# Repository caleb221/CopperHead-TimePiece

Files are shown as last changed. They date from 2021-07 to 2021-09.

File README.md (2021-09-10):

# CopperHead-TimePiece
A 'Retro' ESP32 Based Smart watch using an HPDL-1414 and an .91'' OLED <br>**42x35mm**<br>
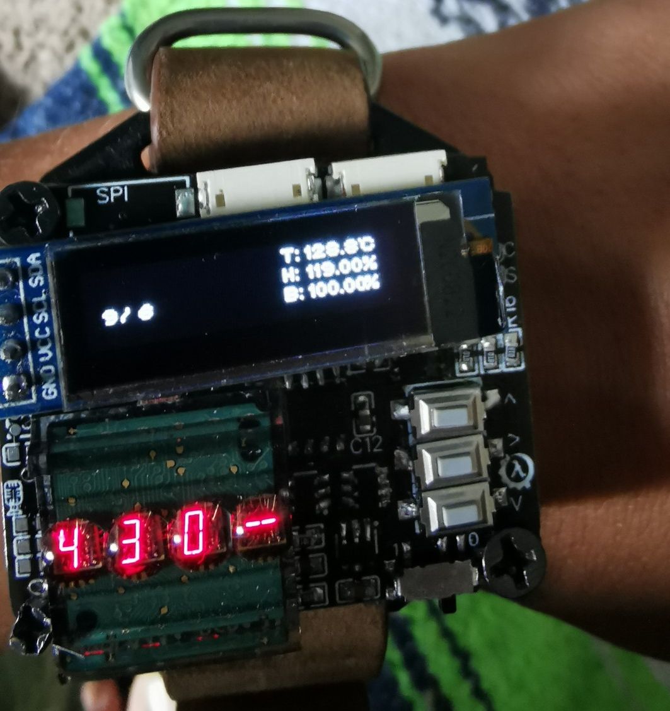
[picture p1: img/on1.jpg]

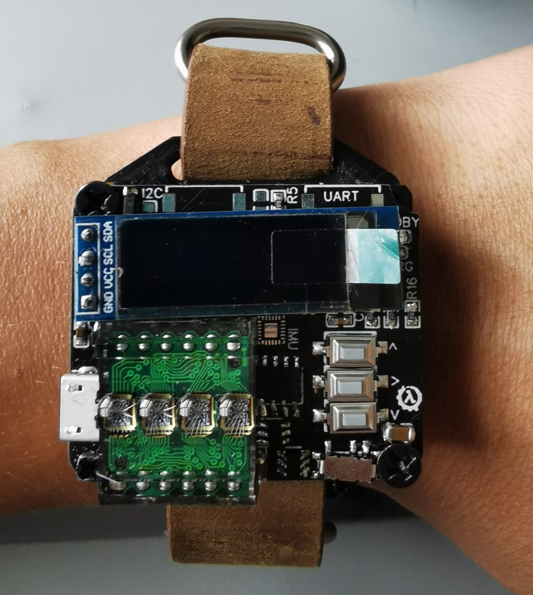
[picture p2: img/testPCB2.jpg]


# IN PROGRESS
    --> BE SURE TO GET THE MOST UP TO DATE FILES AS THERE ARE SEVERAL ITERATIONS
    --> TEST MEMS MIC / IMU    
  Add personal Assistant with Mic using:
  <a href="https://www.survivingwithandroid.com/esp32-tensorflow-micro-speech-i2s-external-microphone/">ESP32-I2S WITH TENSORFLOW MICRO</a>

# Features
  Watch based around the ESP32 and HPDL1414. <br>
  Update time with NTP in known WiFi Areas (SSIDS/Passwords saved in SPIFFS JSON file) <br>
  DS1307 Real Time Module<br>
  Temperature and Humidity readings <br>
  Battery Charging and monitoring <br>
  MPU-950 Gyroscope/Accelerometer/Magenetometer (Compass)<br>
  MEMS Analog Microphone (to be used with TF-Lite Speech Recognition for wake words / personal assistant)<br>
  I2C/UART/SPI modular breakout for future sensors/ICs <br>
  Chrome Dino Game  <br>
  Space Invaders Game <br>
  Update WiFi networks and system time over a hosted website incase there are no known networks around and time is off.
   
# Schematic
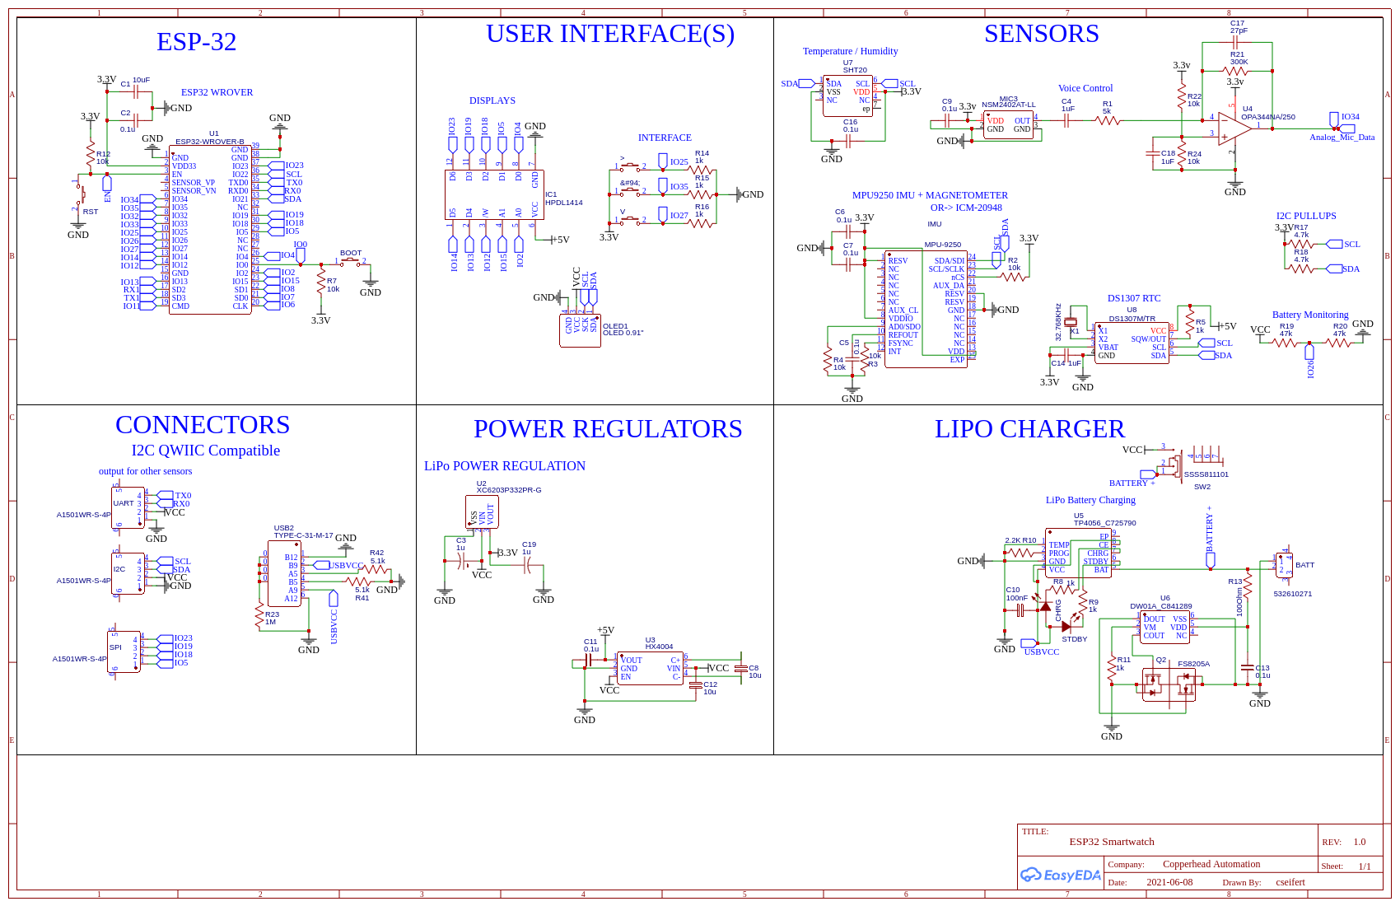
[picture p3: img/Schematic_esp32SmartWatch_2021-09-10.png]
  
  
  
       
# Hardware
     ESP32 Wrover-B (4 or 8Mb) 
     HPDL-1414 Segmented Display  
     0.91'' OLED Display 
     DS1307 RTC Module
     SHT20 Temperature/Humidity Sensor 
     MPU-9250 Gyroscope/Accelerometer/Magnetometer 
     Tactile Switches (3 with 2 optional) 
     Various SMD Resistors/Capacitors (0603 Resistors)
     32.768kHz ±20ppm Crystal
     TP4056 
     DW01A  
     FS8205A
     HX4004 DC-DC Step up (LDO) 
     XC6203P332PR DC-DC Regulator (LDO)
     GMA3722H11-F42 MEMS Analog Microphone
     OPA344NA Analog Op Amp
     TYPE-C-31-M-17 USB-C Connector (6-Pin Power Only) 
     3.7v 320mAh/420mAh LiPo Battery
     ZH1.5 SMD Right Angle Connectors (4 and 2 pin female)  
     right angle tactile switch
     Tactile Buttons
     USB-C Power connector
     PCB (from Gerber File attached)
     M3x4mm Screws (X6)
     10mm Brass Standoffs (X3)
     3D-Printed Case (STL file)
     Watch Strap (20mm Thick)
     External FTDI/CP2102 USB-TTL converter
     
 <a href ="http://www.farnell.com/datasheets/76528.pdf">HPDL-1414 Datasheet</a>

# Software
     The ESP32 holds a SPIFFS filesystem containing the following files:
               --> index.html (should erase when BLE works) 
               --> userConf.json (known WiFi/Passwords) user edit on upload/web interface
               --> sysTime.json (last updated time) user edit on upload/web interface
               --> highScores.json (high score info for games *UNTESTED*)
     The ESP32 spends most of its time in deep sleep, unless woken from the UI buttons
     Upon wakeup the ESP32 will update the OLED with month, day of week, battery level, temperature, and humidity.
     The HPDL-1414 is used for time in HH:MM format. "1259" = 12:59
     There is also a timer on the watch so that it cannot be awake for too long (always default to sleep)
     The Chrome 404 Dino Game (made for this watch / screen / UI)
     Space Invaders (made for this watch / screen / UI)

   <a href="https://github.com/caleb221/ArduinoChromeDinoGame">My Arduino  Chrome Dino Game</a> 

# Gerber / BOM
      check out the Manufacturing Files folder for these!
      --> Gerber_PCB_esp32SmartWatch_2.zip  2-Layer Board **OLD VERSION**
      --> Gerber_PCB_esp32SmartWatch_3.zip  4-Layer Board **MOST CURRENT**
      I got most normal components at LCSC (excluding those listed below)
      PCB made at JLCPCB
      --> I soldered on the components but I'm sure the SMT Assembly is an option given you match up the BOM
 <br>
 <a href="https://lcsc.com/">LCSC Components</a><br>
 <a href="https://jlcpcb.com/">JLCPCB Pcb Manufacturing</a>
 <br><br>
 
  **THINGS NOT BOUGHT FROM LCSC:** 
 
 <a href ="https://www.amazon.com/dp/B08215N9R8/ref=emc_b_5_t" >3.7v 320mAh LiPo (Amazon)</a>
 **OR**
 <a href = "https://www.adafruit.com/product/4236">3.7 420mAh Lipo (Adafruit)</a><br>
 <a href ="https://www.amazon.com/dp/B08NGL1PQ2?psc=1&ref=ppx_yo2_dt_b_product_details">0.91'' OLED Display (Amazon)</a><br>
 <a href ="https://www.amazon.com/dp/B076BNC876?psc=1&ref=ppx_yo2_dt_b_product_details"> 20mm Leather Watch Strap (Amazon) </a><br>
 <a href="https://www.amazon.com/Uxcell-a14050600ux1057-Female-Hexagon-Standoff/dp/B00NQ87PVK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"> Brass Standoffs (Amazon)</a><br>
 <a href ="https://www.amazon.com/10-M3-0-5-4mm-Countersunk-MonsterBolts/dp/B07983R7XC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">M3 x4mm black Screws (Amazon)</a><br>
 <a href ="https://www.ebay.com/itm/303806129405?ssPageName=STRK%3AMEBIDX%3AIT&_trksid=p2060353.m2749.l2649"> EBAY HPDL-1414 (not guaranteed)</a><br>**EBAY AND AMAZON LINKS/PRODUCTS EXPIRE, YOU'LL NEED TO SEARCH FOR HPDL-1414 WHEREVER YOU NORMALLY SOURCE ODD COMPONENTS**<br> 

# TODO
     Get a stencil <br>
     Make an addon with the modular breakouts (I2C/ UART)
               --> Raspberry pi 0 (with something cool)
               --> SD Card (SPI in Software, would need both ports)
               --> Geiger counter
               --> C02 Monitor
               --> Smart home / MQTT control (would need a UI sub directory added)
               --> Connect LoRa and control the smart farm! (this would take awhile)
# Would Be Nice:
     Waterproof case (hasunCast/PCB potting/ Resin)
     Glass over screens
     smaller PCB (if possible)
     bigger battery (needs to fit inside the case!)
     move buttons to bottom layer / change to right angled tactile buttons
     Use external RTC (DS3231 /C9866) OR (PCF8563M / C434478)
                      (part  / LCSC)
     Android Application (web UI takes place of this for now)
     Use BLE Server implementation (commented out at bottom of code) --> 
          accepts JSON data and updates internal filesystem
          Web Server uses same functions and tested, BLE with JSON is UNTESTED

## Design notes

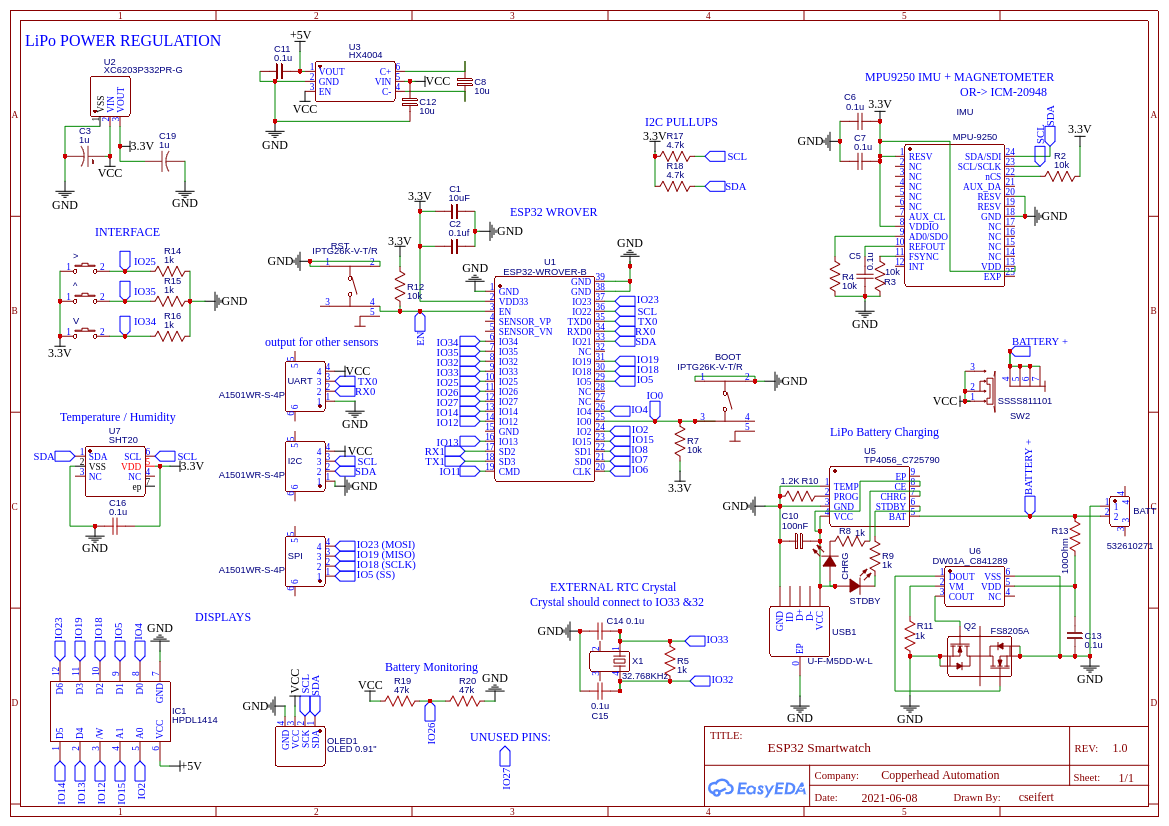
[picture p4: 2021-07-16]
img/Schematic_esp32SmartWatch_2021-07-16.png

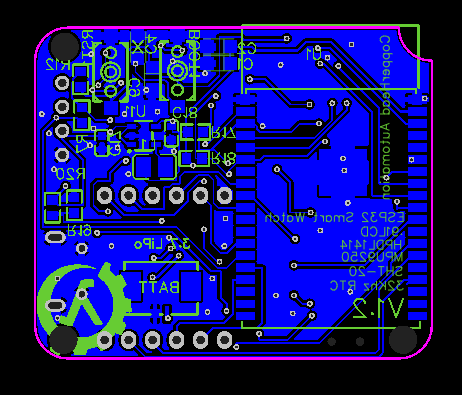
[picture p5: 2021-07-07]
img/PCBeditorBACK.png

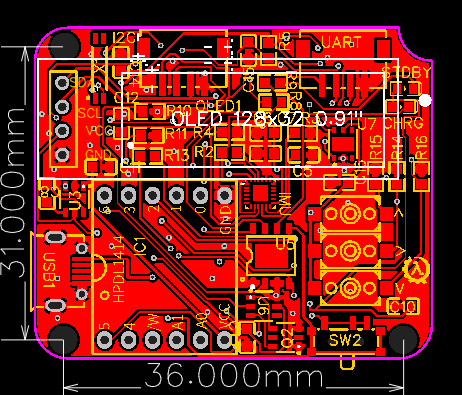
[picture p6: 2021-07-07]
img/PCBeditorFRONT.png

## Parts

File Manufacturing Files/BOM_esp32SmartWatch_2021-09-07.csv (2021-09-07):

ID | Name | Designator | Footprint | Quantity | Manufacturer Part | Manufacturer | Supplier | Supplier Part | Price
1 | K2-3.6×6.1_SMD | ^,>,V | KEY-SMD_2P-L6.2-W3.6-LS8.0 | 3 | K2-1107ST-A4SW-06 |  | LCSC | C118141 | 0.056
2 | 532610271 | BATT | CONN-SMD_532610271 | 1 | 532610271 | MOLEX | LCSC | C189700 | 0.112
3 | IPTG26K-V-T/R | BOOT,RST | SW-SMD_IPTG26K | 2 | IPTG26K-V-T/R | Diptronics | LCSC | C495953 | 0.254
4 | 10uF | C1 | CASE-A_3216 | 1
5 | 0.1uf | C2 | CASE-A_3216 | 1
6 | 1u | C3,C19 | CASE-A_3216 | 2
7 | 1uF | C4,C18 | C0603 | 2
8 | 0.1u | C5,C6,C7,C9,C16,C11,C13 | C0603 | 7
9 | 10u | C8,C12 | C0603 | 2
10 | 100nF | C10 | C0603 | 1
11 | 12pF | C14,C15 | C0603 | 2
12 | 27pF | C17 | C0603 | 1
13 | LED-0603_R | CHRG,STDBY | LED0603_RED | 2 | 19-217/R6C-AL1M2VY/3T | EVERLIGHT(台湾亿光) | LCSC | C72044 | 0.014
14 | A1501WR-S-4P | I2C,SPI,UART | CONN-SMD_A1501WR-S-4P | 3 | A1501WR-S-4P | Changjiang Connectors | LCSC | C225169 | 0.145
15 | HPDL1414 | IC1 | HPDL1414 | 1
16 | MPU-9250 | IMU | QFN-24_L3.0-W3.0-P0.40-BL-EP | 1 | MPU-9250 | InvenSense | LCSC | C71459
17 | NSM2402AT-LL | MIC3 | MIC-SMD_L3.8-W2.2-TL | 1 | NSM2402AT-LL | ReliaPro | LCSC | C140704 | 0.328
18 | OLED 0.91" | OLED1 | OLED_0.91_128X32 | 1 | OLED 0.91" 128x32 |  | LCSC | C91220 | 3.318
19 | FS8205A | Q2 | SOT-23-6_L2.9-W1.6-P0.95-LS2.8-BR | 1 | FS8205A | FORTUNE | LCSC | C32254 | 0.153
20 | 5k | R1 | R0603 | 1
21 | 10k | R2,R3,R4,R7,R12,R22,R24 | R0603 | 7
22 | 1k | R8,R9,R11,R14,R15,R16 | R0603 | 6
23 | 2.2K | R10 | R0603 | 1
24 | 100Ohm | R13 | R0603 | 1
25 | 4.7k | R17,R18 | R0603 | 2
26 | 47k | R19,R20 | R0603 | 2
27 | 300K | R21 | R0603 | 1
28 | 1M | R23 | R0603 | 1
29 | 5.1k | R41,R42 | R0603 | 2
30 | SSSS811101 | SW2 | SW-SMD_SSSS811101 | 1 | SSSS811101 | ALPS | LCSC | C109335 | 0.12
31 | ESP32-WROVER-B | U1 | WIFIM-SMD_39P-L31.4-W18.0-P1.27 | 1 | ESP32-WROVER-B | Espressif Systems | LCSC | C503591 | 3.903
32 | XC6203P332PR-G | U2 | SOT-89-3_L4.5-W2.5-P1.50-LS4.2-BR | 1 | XC6203P332PR-G | Torex Semicon | LCSC | C190503 | 0.243
33 | HX4004 | U3 | SOT-23-6_L2.9-W1.6-P0.95-LS2.8-BR | 1 | HX4004 | HEXIN | LCSC | C172355 | 0.135
34 | OPA344NA/250 | U4 | SOT-23-5_L3.0-W1.7-P0.95-LS2.8-BR | 1 | OPA344NA/250 | TI | LCSC | C131974 | 1.411
35 | TP4056_C725790 | U5 | ESOP-8_L4.9-W3.9-P1.27-LS6.0-BL-EP | 1 | TP4056 | UMW(Youtai Semiconductor Co., Ltd.) | LCSC | C725790 | 0.061
36 | DW01A_C841289 | U6 | SOT-23-6_L2.9-W1.6-P0.95-LS2.8-BR | 1 | DW01A | Shenzhen Fuman Elec | LCSC | C841289 | 0.052
37 | SHT20 | U7 | DFN-6_L3.0-W3.0-P0.95-TR-EP | 1 | SHT20 | Sensirion | LCSC | C53865 | 1.646
38 | TYPE-C-31-M-17 | USB2 | USB-C-SMD_10P-P1.00-L6.8-W8.9 | 1 | TYPE-C-31-M-17 | Korean Hroparts Elec | LCSC | C283540 | 0.194
39 | 32.768KHz | X1 | MC-146_4P-L6.7-W1.5-P0.85-TL | 1 | Q13MC1462000200 | EPSON | LCSC | C15482 | 0.443

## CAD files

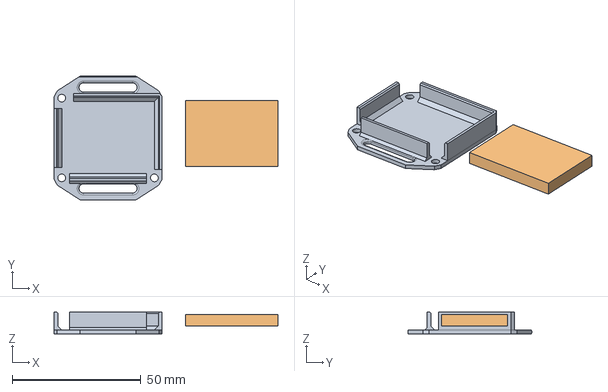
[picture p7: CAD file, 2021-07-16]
STL/watchCaseV2_STRAP_OUTSIDE.FCStd
87.0 x 48.0 x 8.50 mm

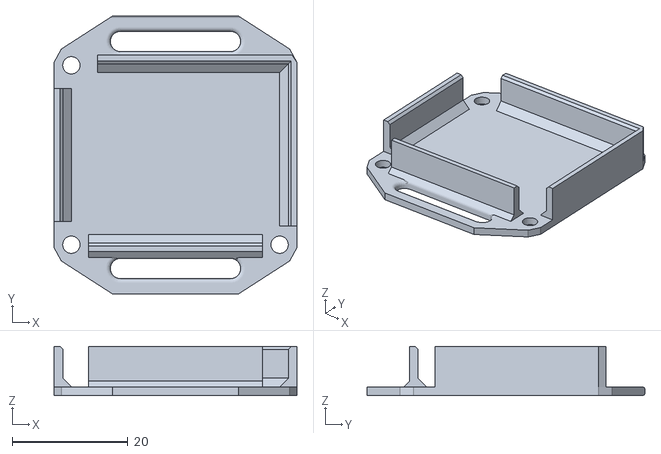
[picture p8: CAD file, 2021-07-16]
STL/watchCaseV2.stl
42.0 x 48.0 x 8.50

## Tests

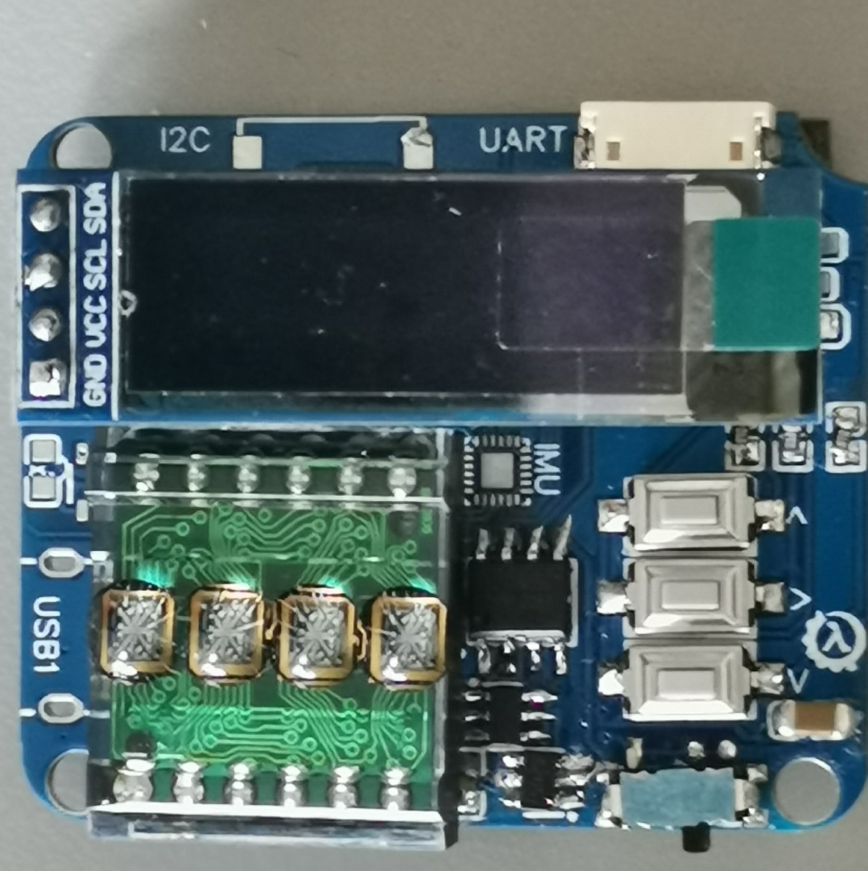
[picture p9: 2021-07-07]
img/testPCB1.jpg

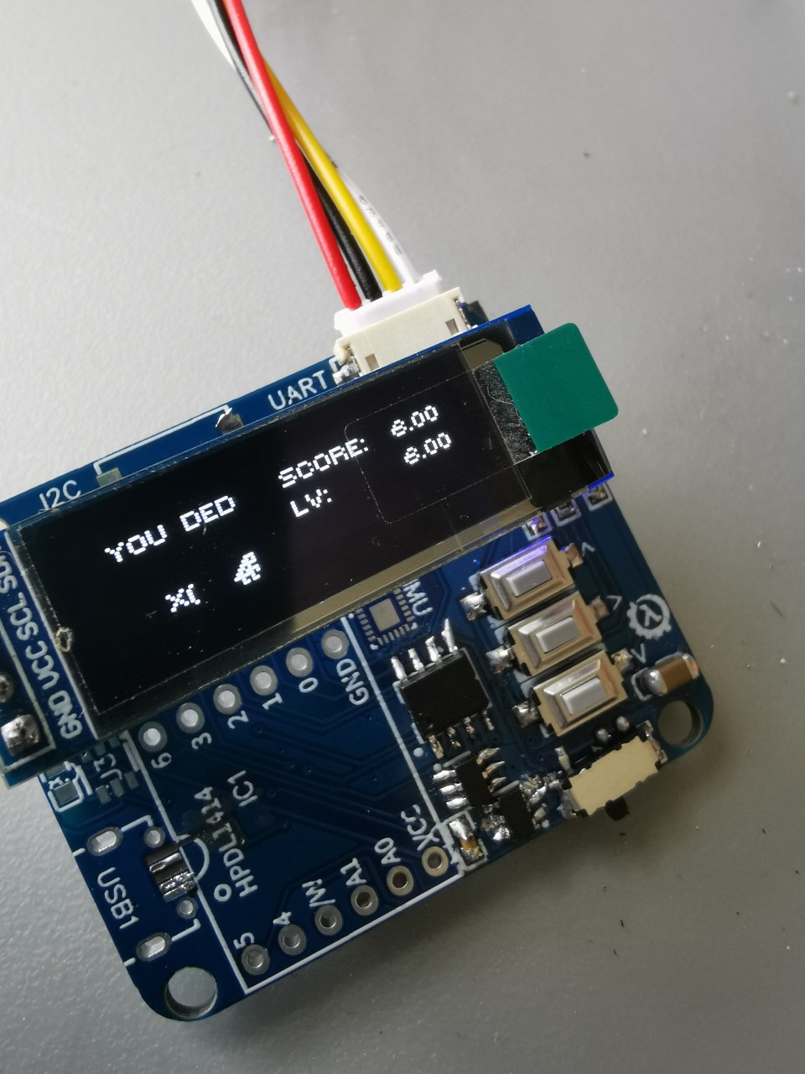
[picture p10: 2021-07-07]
img/dinoChromeGameTest.jpg

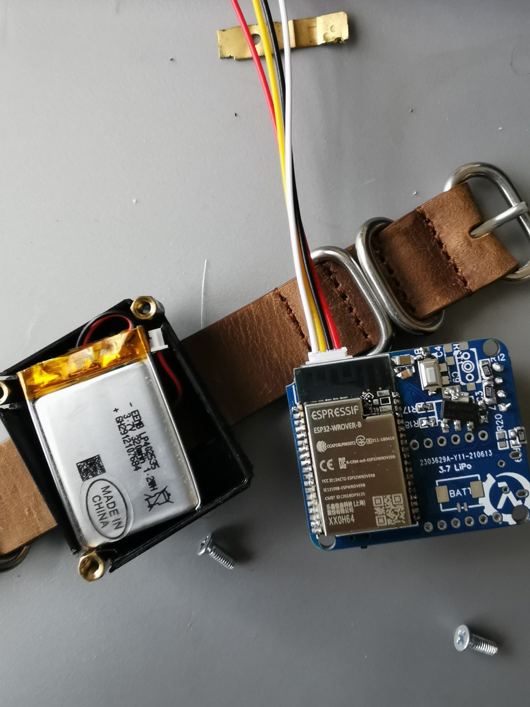
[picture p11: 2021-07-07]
img/espTesterPCB1.jpg

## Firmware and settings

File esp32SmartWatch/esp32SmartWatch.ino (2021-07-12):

//CpHd's TimePiece
// if WiFi is known auto update
// SPIFFS
// sysTime.json -->
// userConf.json --> saved SSID/Passwords
 //       --> probably not a good idea to store plaintext passwords
// highScores.json --> game highscores
// 
// 0.91'' 128x32 I2C OLED
// HDLP1414 DIP12 Segmented LED Display
// IMU --> X,Y,Z, Compass (HARD TO SOLDER)
// SHT20 --> Temperature / Humidity I2C
//
// dinoGame.ino --> Arduino version of Chrome Dino Game (made for .91 screen)
// spaceInvaders.ino --> Attached at bottom

/*
=======================================
          PINOUT
=======================================
IO - CONNECTION
02 - HPDL1414
04 - HPDL1414
05 - HPDL1414
12 - HPDL1414
13 - HPDL1414
14 - HPDL1414
15 - HPDL1414
18 - HPDL1414
19 - HPDL1414
21 - SDA
TX - TX
RX - RX
22 - SCL
23 - HPDL1414
25 - BUTTON SELECT
27 - FREE/NC
26 - BATTERY MONITOR
32 - CRYSTAL
33 - CRYSTAL
34 - BUTTON DOWN
35 - BUTTON UP 
 */
 
#include <Wire.h>
#include <HPDL1414.h>
#include <driver/adc.h>
#include "uFire_SHT20.h"

//#include "MPU9250.h"

#include<stdio.h>
#include "U8g2lib.h"
#include "SPIFFS.h"
#include <soc/rtc.h>
#include<time.h>
#include "time.h"

//connectivity
//#include<BLEDevice.h>
//#include<BLEUtils.h>
//#include<BLEServer.h>
#include<WiFi.h>
#include<WebServer.h>
#include<WiFiUdp.h>
#include<ArduinoJson.h>
#include "ESPAsyncWebServer.h"
#include "AsyncJson.h"
//#include <ESPmDNS.h>

//HARDWARE
#define BTN_UP 35
#define BTN_SL 34
#define BTN_DN 32


#define BTN_BTMASKOLD 0xD00000000
#define BTN_BTMASK 0xC20000000
//Binary mask:
//110100000000000000000000000000000000 OLD
//110000100000000000000000000000000000 NEW
#define BATT_ADC 33

//HPDL1414:

//BOARD:    D5,D4,W,A1,A0
//ESP:      14,13,12,15,2
//        ===================
//          D0,D1,D2,D3,D6
//          4, 5, 18,19,23

const byte dataPins[7] = {4, 5, 18, 19,13,14,23}; // Segment data pins: D0 - D6
const byte addrPins[2] = {15, 2}; // Segment address pins: A0, A1
const byte wrenPins[] = {12}; // Write Enable pins (left to right)


//https://www.uuidgenerator.net/

//Temperature read Characteristic: 0x2A1C
//Battery: 0x180F
//User Data: 0x181C 
//0x2A08 Date Time

#define uS_TO_S_FACTOR 1000000  //Conversion factor for micro seconds to seconds
#define TIME_TO_SLEEP 30//Seconds, update on the minute

#define CALIBRATE_ONE(cali_clk) calibrate_one(cali_clk, #cali_clk)

U8G2_SSD1306_128X32_UNIVISION_F_SW_I2C u8g2(U8G2_R0, /* clock=*/ SCL, /* data=*/ SDA, /* reset=*/ U8X8_PIN_NONE);
//.91 -->> SSD1306
HPDL1414 dopeScreen(dataPins, addrPins, wrenPins, sizeof(wrenPins));
uFire_SHT20 sht20;

const char* ntpServer = "pool.ntp.org";
const long  gmtOffset_sec = -18000;// For UTC -5.00 : -5 * 60 * 60 : -18000;
const int   daylightOffset_sec = 3600;

//char bleDataIn[300];
AsyncWebServer server(80);
bool didWebUpdate=false;
bool isWebServing=false;
//SENSOR DATA
float temperature;
float humidity;
float battLevel;

//GAME CONSTANTS
#define IMG_WIDTH 8
#define IMG_HEIGHT 8
#define IMG_SIZE 8
#define HEIGHT 32 //pixel screen height
#define DNR_CRTL 15 //Control Button Pin 
int ENEMY_START = 100;//X Starting for enemy rendering
int WIDTH=128;//pixel screen width
int FLOOR_LEVEL=22;
int JUMP_PIXELS=5;
int ENEMY_PAD = 20;

//============================================================================
//                   JSON/SPIFFS FILE SYSTEM HANDLING
//============================================================================

 bool updateJsonTime(int yr,int mnt,int dy,int hr, int minute,int sec)
{
  if(!SPIFFS.begin(true)){
            u8g2.clearBuffer();
        u8g2.drawStr(5,10,"SPIFFS");
        u8g2.drawStr(5,18,"ERROR X(");
        u8g2.sendBuffer(); 
        delay(3000);
    return false;
  }
  File rawFile = SPIFFS.open("/sysTime.json","w");
  if(!rawFile){
                u8g2.clearBuffer();
        u8g2.drawStr(5,10,"JSON SPIFFS");
        u8g2.drawStr(5,18,"ERROR X(");
        u8g2.sendBuffer(); 
        delay(3000);
         return false;
  }
     
  char buffer1[124];
  DynamicJsonDocument updateTimeDoc(124);
  updateTimeDoc["yr"]=yr;
  updateTimeDoc["mnt"]=mnt;
  updateTimeDoc["dy"]=dy;
  updateTimeDoc["hr"]=hr;
  updateTimeDoc["minute"]=minute;
  updateTimeDoc["sec"]=sec;
  serializeJson(updateTimeDoc,buffer1);
  rawFile.print(buffer1);
  rawFile.close();
  return true;
 }
 
bool updateJsonConfig(const char* newSSID,const char* newPWD)
{
  
  if(!SPIFFS.begin(true))     
      return false;
 File rawConf = SPIFFS.open("/userConf.json","r");
  
  if(!rawConf)
    return false;

    //CHANGE TO MATCH ARRAY
  StaticJsonDocument<1024> conf;
    StaticJsonDocument<1024> newConf;

  char buffer1[1024];
  
  DeserializationError err = deserializeJson(conf,rawConf);
  if(err)
    return false;
  JsonArray wIds = conf["W"].as<JsonArray>();
  JsonArray pIds = conf["P"].as<JsonArray>();
  
  wIds.add(newSSID);
  pIds.add(newPWD);
  
  rawConf.close();
  
  File rewriteFile = SPIFFS.open("/userConf.json","w");

  serializeJson(conf,buffer1);
  rewriteFile.print(buffer1);
  rewriteFile.close();
  return true;
}


void updateFromJSON()
{
    if(!SPIFFS.begin(true)){
    Serial.println("An Error has occurred while mounting SPIFFS");
    return ;
  }
  
  File rawFile = SPIFFS.open("/sysTime.json");
  
  if(!rawFile)
      return;
  StaticJsonDocument<256> jsonTime;
  DeserializationError err = deserializeJson(jsonTime,rawFile);
  
  if(err)
     Serial.println("JSON TIME OPEN ERR");

 int year=jsonTime["yr"];
 int month= jsonTime["mnt"];
 int day= jsonTime["dy"];
 int hour=jsonTime["hr"];
 int minute=jsonTime["minute"];
 int second=jsonTime["sec"];
  
  struct tm newTimeinfo;
  newTimeinfo.tm_year=year;
  newTimeinfo.tm_mon=month;
  newTimeinfo.tm_mday=day;
  newTimeinfo.tm_hour=hour;
  newTimeinfo.tm_min=minute;
  newTimeinfo.tm_sec=second;
  time_t tjson = mktime(&newTimeinfo); 
  //struct timeval updatr ={.tv_sec = tjson};

 
 struct tm * timeinfo;
 time_t t;
 timeval tval;
 gettimeofday(&tval, NULL);
  //convert to time values we can actually use
  t = tval.tv_sec;           //seconds since epoch
  //timeinfo = localtime(&t);  //time struct


if(t<tjson)//make sure JSON is more current
 updateSysTime(year,month,day,hour,minute,second);
//else //make JSON more current
  //updateJsonTime(year,month,day,hour,minute,second);

}

void updateSysTime(int year,int month,int day,int hour,int minute,int seconds)
{
  setenv("TZ", "EST5EDT4,M3.2.0/02:00:00,M11.1.0/02:00:00", 1);
  tzset();
  struct tm newTimeinfo;
  newTimeinfo.tm_year=year;
  newTimeinfo.tm_mon=month;
  newTimeinfo.tm_mday=day;
  newTimeinfo.tm_hour=hour;
  newTimeinfo.tm_min=minute;
  newTimeinfo.tm_sec=seconds;
/*
  Serial.print("\n======TIME UPDATER=====\n");
  Serial.print(year);
  Serial.print("  ");
  Serial.print(month);
  Serial.print("  ");
  Serial.print(hour);
  Serial.print(" : ");
  Serial.print(minute);
  Serial.println("\n==============");
*/
  time_t t = mktime(&newTimeinfo); 
  struct timeval updatr ={.tv_sec = t};
  settimeofday(&updatr,NULL);
}

void stopWiFi()
{
     //WiFi.isEnabled()
     WiFi.disconnect(true);
     WiFi.mode(WIFI_OFF);
     u8g2.clearBuffer();
     u8g2.drawStr(5,10,"Turning WiFi");
     u8g2.drawStr(5,20,"OFF");
     u8g2.sendBuffer();
     delay(3000);  
isWebServing=false;
}


void tryWiFi_time()
{

  //make sure we have the antenna!!
  //stopBLE();
  delay(100);

  if(!SPIFFS.begin(true))
  {
        u8g2.clearBuffer();
        u8g2.drawStr(10,10,"SPIFFS  ERR");
        u8g2.sendBuffer();    
        delay(3000);
        return;  
  }
  
    File rawConf = SPIFFS.open("/userConf.json");
  
    if(!rawConf)
    {
        u8g2.clearBuffer();
        u8g2.drawStr(10,10,"JSON  ERR");
        u8g2.sendBuffer();    
        delay(3000);
        return;    
    }

    //CHANGE TO MATCH ARRAY
  StaticJsonDocument<256> conf;
  DeserializationError err = deserializeJson(conf,rawConf);
  
      if(err)
      {
        u8g2.clearBuffer();
        u8g2.drawStr(10,10,"JSON  ERR");
        u8g2.sendBuffer();
        delay(3000);    
      }
      
  JsonArray wIds = conf["W"].as<JsonArray>();
  JsonArray pIds = conf["P"].as<JsonArray>();
  int pCounter=0;
  size_t pSize = pIds.size();
  for(JsonVariant wNow :wIds)
  {
    const char* w = wNow.as<char*>();
    const char* p = pIds[pCounter].as<char*>();

    int connectCount=0;
    WiFi.begin(w,p);
      while (connectCount < 5) 
      {
        delay(500);
        connectCount++;
        u8g2.clearBuffer();
        u8g2.drawStr(0,10,"Connecting to..");
        u8g2.drawStr(20,18,w);
        u8g2.sendBuffer();
        }
      pCounter++;
      if(WiFi.status() == WL_CONNECTED)
       break;
  } 
  rawConf.close();
      
  if(WiFi.status() == WL_CONNECTED) 
  {   
    struct tm timeinfo;

    Serial.println("getting NTP Time");
    configTime(gmtOffset_sec, daylightOffset_sec, ntpServer);
    char* myIP = (char *) WiFi.localIP().toString().c_str();
        u8g2.clearBuffer();
        u8g2.drawStr(5,10,"Connected at");
        u8g2.drawStr(5,18,myIP);
        u8g2.drawStr(5,24,"getting NTP Time");
        u8g2.sendBuffer();
        delay(2000);
  
  while(!getLocalTime(&timeinfo)){
    Serial.println("Failed to obtain time");
    configTime(gmtOffset_sec, daylightOffset_sec, ntpServer);
    delay(100);
    }//make sure NTP updates itself


  updateSysTime( (timeinfo.tm_year),
                  (timeinfo.tm_mon),
                  (timeinfo.tm_mday),
                  timeinfo.tm_hour,
                  timeinfo.tm_min,
                  timeinfo.tm_sec
            );
   bool didUpdate = updateJsonTime((timeinfo.tm_year),
                  (timeinfo.tm_mon),
                  (timeinfo.tm_mday),
                  timeinfo.tm_hour,
                  timeinfo.tm_min,
                  timeinfo.tm_sec
            );

    char* updateStat="NO";
    if(didUpdate)
      updateStat="TRU";
        u8g2.clearBuffer();
        u8g2.drawStr(10,18,"NTP Time Updated:");
        u8g2.drawStr(10,24,updateStat);
        u8g2.sendBuffer();
        delay(2000);
  }
  else
  {
        u8g2.clearBuffer();
        u8g2.drawStr(5,10,"No WiFi Found");
        u8g2.drawStr(5,18,"unable to update");
        u8g2.drawStr(5,24,"find a known network! X(");
        u8g2.sendBuffer();
        delay(5000);
  
  }
stopWiFi(); 
}

void espSleep()
{

  //Check time, update the SPIFFS JSON time
  // file, and save it before we sleep
  //updateFromJSON();
  
  //update LED SCREEN INCASE I NEED TIME WHILE ESP IS SLEEPING
  //updateHPDL();
  //SAVE POWER, OLED OFF!
  u8g2.clearBuffer();

  u8g2.drawStr(20,18,"ZZZZ...");
  u8g2.sendBuffer();
  //SLEEP FINALLY!            
  esp_sleep_enable_ext1_wakeup(BTN_BTMASKOLD,ESP_EXT1_WAKEUP_ANY_HIGH);
  esp_sleep_enable_timer_wakeup(TIME_TO_SLEEP * uS_TO_S_FACTOR);
  esp_deep_sleep_start();
}

void IRAM_ATTR btnUP_INTRR()
{
  menuHandler(1);  
}

void IRAM_ATTR btnSL_INTRR()
{
  menuHandler(0);
}

void IRAM_ATTR btnDN_INTRR()
{
  menuHandler(2);  
}

void setup() {
  // put your setup code here, to run once:
 Serial.begin(115200);
 
  pinMode(BTN_DN,INPUT);
  pinMode(BTN_UP,INPUT);
  pinMode(BTN_SL,INPUT);
  //attachInterrupt(BTN_DN, btnDN_INTRR, HIGH);
  //attachInterrupt(BTN_UP, btnUP_INTRR, HIGH);
 // attachInterrupt(BTN_SL, btnSL_INTRR, HIGH);
  
 ///Wire.begin(); 
 u8g2.begin();
 //updateFromJSON();

  /*
   //=====================
  //  32KhZ Crystal setup
  rtc_clk_32k_bootstrap(512);
  rtc_clk_32k_bootstrap(512);
  rtc_clk_32k_enable(true);
  uint32_t cal_32k = CALIBRATE_ONE(RTC_CAL_32K_XTAL);
  rtc_clk_slow_freq_set(RTC_SLOW_FREQ_32K_XTAL);
  //=====================
  //adc2_config_width(ADC_WIDTH_12Bit);
  // Battery Monitor
  adc2_config_channel_atten(ADC2_CHANNEL_9, ADC_ATTEN_0db); //set reference voltage to internal
  //ADC2_CH9 --> GPIO 26
  esp_sleep_enable_timer_wakeup(TIME_TO_SLEEP * uS_TO_S_FACTOR); 

 Wire.begin(); 
 u8g2.begin();
 sht20.begin();
 dopeScreen.begin();
 dopeScreen.printOverflow(true);
 updateFromJSON();
 checkSensors();
 updateHPDL(); 
 menuHandler(0);
   
*/
  //setupBLE();
 //tryWiFi_time();//see if we're in a known area for updates
  //espSleep();
    menuHandler(0);

Serial.println("all setup!");

}

void loop() {
  // put your main code here, to run repeatedly:

  menuHandler(0);
  delay(500);
  //updateFromJSON();
  //updateHPDL();   
  //espSleep();
}

//============================================================================
//                      MENU / UI INTERFACE
//============================================================================
void menuHandler(int dir)
{

//detach interrupts
detachInterrupt(BTN_UP);
detachInterrupt(BTN_SL);
detachInterrupt(BTN_DN);
int MAX_DIR=7;//move this up as more directories are added
            // ORRR...add another similar function to this with subdirs..
char temp[5];
int selection =0;
    struct tm * timeinfo;
     time_t t;
     timeval tval;
     gettimeofday(&tval, NULL);
     //convert to time values we can actually use
     t = tval.tv_sec;           //seconds since epoch
     timeinfo = localtime(&t);  //time struct
     int day=timeinfo->tm_mday;
     int month=timeinfo->tm_mon;
     month++;//no such thing as a 0th month

    u8g2.setFont(u8g2_font_tinytim_tf);

//ADD TIMER ALSO (2-3 SECONDS)
const long menuTimeout = 55;//about 5 seconds          
unsigned long counter = 0;      
bool hasSelection = false;

while (!hasSelection )
{
  
  u8g2.clearBuffer();
  if(digitalRead(BTN_UP)==HIGH)
    dir++;
  
  if(digitalRead(BTN_DN)==HIGH)
    dir--;
  if(dir >MAX_DIR) 
    dir=0;
  else if(dir <= -1)
    dir = MAX_DIR;
    
  switch(dir)
  {
    case 0:
    //OLED Default screen:
    //       T:XX*c H:XX%
    //D:DD M:MM     B:XX%
    
    dtostrf(temperature,5,2,temp);
    u8g2.drawStr(80,8,"T:");
    u8g2.drawStr(90,8,temp);
    
    u8g2.drawStr(80,16,"H:");
    dtostrf(humidity,5,2,temp);
    u8g2.drawStr(90,16,temp);

    dtostrf(battLevel,5,2,temp);
    u8g2.drawStr(90,24,temp);
    u8g2.drawStr(80,24,"B:");

    //units
    u8g2.drawStr(114,8,"C");
    u8g2.drawStr(114,16,"%");
    u8g2.drawStr(114,24,"%");
    //Month / Day  
    dtostrf(month,2,0,temp);
    u8g2.drawStr(2,22,temp);
    u8g2.drawStr(14,22,"/");
    dtostrf(day,2,0,temp);
    u8g2.drawStr(16,22,temp);
    selection =0;
     /*
     if(bleServerEnabled)
     {
      u8g2.drawStr(25,16,"BLE IS ON!");
      selection=255;
     }
     */
    if(isWebServing)
    {
        u8g2.clearBuffer();
        u8g2.drawStr(5,5,"WebServer Enabled!");
        u8g2.drawStr(5,15,"PW: 123456789");
        u8g2.drawStr(5,24,"-->>  192.168.4.1");
                            //192.168.4.1
        selection=255;
        
    }
    break;
case 1://scan wifi
        u8g2.drawStr(0,10,"Scan for known");
        u8g2.drawStr(20,18,"WiFi Networks");
        u8g2.drawStr(20,24,"and update time");
        selection=1;
    break;
case 2://open webServer
         u8g2.drawStr(5,10,"Start the WiFi Server");
         u8g2.drawStr(5,20,"To Load New Config!");       
         selection=2;
    break;
case 3: //IMU stuff 
          u8g2.drawStr(0,10,"IMU (currently unavailable)");
          selection =0;
   break;
case 4://games
        u8g2.drawStr(20,10,"Chrome Dino Game!");
          renderEnemy(1,80,20);
          selection =4;
   break;
case 5:
        u8g2.drawStr(20,10,"Space Invaders!");
        renderEnemy(5,80,20);
        selection =5;
   break;
case 6:
        u8g2.drawStr(5,15,"Stop the WiFi Server");
        //u8g2.drawStr(5,20,"this saves lots of power!");
        selection=6;
        break;
case 7:

       u8g2.drawStr(5,10,"Start BlueTooth Service");
       u8g2.drawStr(5,20,"Connect with Android App");
        selection=7;
        break;
default:
            u8g2.drawStr(5,10,"END OF MENU");
            u8g2.drawStr(20,18,"PRESS ^^ BUTTON");
    break; 
   }  
    u8g2.sendBuffer();
  //420 69
    counter++;
    hasSelection=digitalRead(BTN_SL);
    if(counter>menuTimeout && !isWebServing) //&& !bleServerEnabled
    {
        selection=0;
        hasSelection=true;
    }

    //delay is used for button debouncing
    //"fake" timer is used to exit menu and enter sleep mode
    delay(100);// transfer internal memory to the display
  
  
  
  }//iterate through whole menu until selection



switch(selection)
{
  case 0:
      //go to sleep??
      espSleep();
  break;
  case 1:
    tryWiFi_time();
  break;
  case 2:
    makeWiFiServer(); 
  break;  
  case 3:
    //IMU STUFF
  break;
  case 4:
      dinoGame();
  break;
  case 5:
      spaceInvaders();
  break;
  case 6:
      //stopBLE();
      stopWiFi();
      break;
  case 7:
      return;
    //setupBLE();
    //handleBle();
  break;
  
  default:
    return;
  break;
 }//end selection to function handler
  
//do something with dir --> open subdir or perform action
}//BTN SELECT


//============================================================================
//                      SENSORS
//============================================================================

void checkSensors()
{
    temperature=sht20.temperature();
    humidity=sht20.humidity();
    battLevel=battery_read();
}

static uint32_t calibrate_one(rtc_cal_sel_t cal_clk, const char *name)
{

    const uint32_t cal_count = 1000;
    const float factor = (1 << 19) * 1000.0f;
    uint32_t cali_val;
    printf("%s:\n", name);
    for (int i = 0; i < 5; ++i)
    {
        printf("calibrate (%d): ", i);
        cali_val = rtc_clk_cal(cal_clk, cal_count);
        printf("%.3f kHz\n", factor / (float)cali_val);
    }
    return cali_val;
}

float battery_read()
{
    //read battery voltage per %
    long sum = 0;                  // sum of samples taken
    float voltage = 0.0;           // calculated voltage
    float output = 0.0;            //output value
    const float battery_max = 3.6; //maximum voltage of battery
    const float battery_min = 2.9; //minimum voltage of battery before shutdown

    float R1 = 47000.0; // resistance of R1 (47K)
    float R2 = 47000.0;  // resistance of R2 (47K)
    int read_raw = 0;
    for (int i = 0; i < 100; i++)
    {
     // sum ADC2_CHANNEL_9
   esp_err_t r = adc2_get_raw( ADC2_CHANNEL_9, ADC_WIDTH_12Bit, &read_raw);
//        sum += adc1_get_voltage(ADC2_CH9);
        sum+=read_raw;   
        delayMicroseconds(1000);
    }
    // calculate the voltage
    voltage = sum / (float)500;
    //voltage = (voltage * 1.1) / 4096.0; //for internal 1.1v reference
    // use if added divider circuit
     voltage = voltage / (R2/(R1+R2));
    //round value by two precision
    voltage = roundf(voltage * 100) / 100;
    Serial.print("voltage: ");
    Serial.println(voltage, 2);
    output = ((voltage - battery_min) / (battery_max - battery_min)) * 100;
    if (output < 100)
        return output;
    else
        return 100.0f;
}



void updateHPDL()
{
  
 dopeScreen.clear();
 //Serial.println("======HPDL UPDATE======");

 struct tm * timeinfo;
 time_t t;
 timeval tval;
 gettimeofday(&tval, NULL);
  //convert to time values we can actually use
  t = tval.tv_sec;           //seconds since epoch
  timeinfo = localtime(&t);  //time struct
  int hour=timeinfo->tm_hour;
  int minute=timeinfo->tm_min;
  int isDaylightSavings=timeinfo->tm_isdst;

//because, murica!
  if(isDaylightSavings >0)
      hour=hour-1;

 //24 to 12 hour conversion  
   if(hour>12)
      hour-=12;

   if (hour==0)
       hour=12;
  
 String hourStr=String(abs(hour));
 String minuteStr = String(minute);
 //USE ALL 4 CHARACTERS ON HPDL
 if(hour < 10)
   hourStr="0"+hourStr;
 if (minute < 10)
    minuteStr ="0"+minuteStr;
    
 String timeNow = hourStr+minuteStr;
 dopeScreen.print(timeNow);  
 //Serial.print(timeNow);
 //Serial.println("\n======DONE!======");
}


//============================================================================
//                      WiFi HTTP SERVER
//============================================================================

AsyncCallbackJsonWebHandler* webTimeHandler = new AsyncCallbackJsonWebHandler("/updateTimeData", [](AsyncWebServerRequest *request, JsonVariant &json) {
  JsonObject newData = json.as<JsonObject>();
        
        int yr= newData["yr"];
        int mnt=newData["mnt"];
        int dy=newData["dy"];
        int hr=newData["hr"];
        int mint=newData["mint"];
        int sec=newData["sec"];
//  curl -i -d '{"yr":1,"mnt":2,"dy":3,"hr":4,"mint":5,"sec":6}'  -H "Content-Type: application/json"  -X POST http://192.168.4.1/updateTimeData
// curl -i  -X GET http://192.168.4.1/getTime   
        
        didWebUpdate = updateJsonTime(yr,mnt,dy,hr,mint,sec);
        updateSysTime(yr,mnt,dy,hr,mint,sec);
       
       String respData;
       
       serializeJson(newData,respData);
       request->send(200, "application/json", respData);
       
        if(didWebUpdate)
          request->send(200, "application/json", respData);
        else
            request->send(400, "application/json", respData);
      });


AsyncCallbackJsonWebHandler* webConfHandler = new AsyncCallbackJsonWebHandler("/addConf", [](AsyncWebServerRequest *request, JsonVariant &json)
{
  JsonObject conf2Add = json.as<JsonObject>();
  const char* newW = conf2Add["W"];
  const char* newP = conf2Add["P"];

  didWebUpdate = updateJsonConfig(newW,newP);

  if(didWebUpdate)
    request->send(200, "text/plain", newW );
  else
    request->send(400,"text/plain", newW);  
});

void webGetSpiffsTime(AsyncWebServerRequest *request) {
  String buff;
  if(!SPIFFS.begin(true)){
    buff= "SPIFFS ERR";
  }
  File rawFile = SPIFFS.open("/sysTime.json","r");
  
  if(!rawFile){
         buff= "FILE ERR";
        }
  while(rawFile.available())
  {
    buff+=char(rawFile.read()); 
  }  
  rawFile.close();
  request->send(200, "application/json", buff );
}
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
